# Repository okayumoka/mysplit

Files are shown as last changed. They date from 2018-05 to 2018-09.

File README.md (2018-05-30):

# MySplit Keyboard

自作の左右分割型キーボードです。
筐体（ケース）、Arduino Micro用ファームウェア、レイアウト変更用ツールのセットです。
ビルド方法はこのREADMEを参照してください。

この自作キーボードは、基盤（PCB）を使わず、空中配線するようになっています。
半田付けの難易度は高くないと思います。

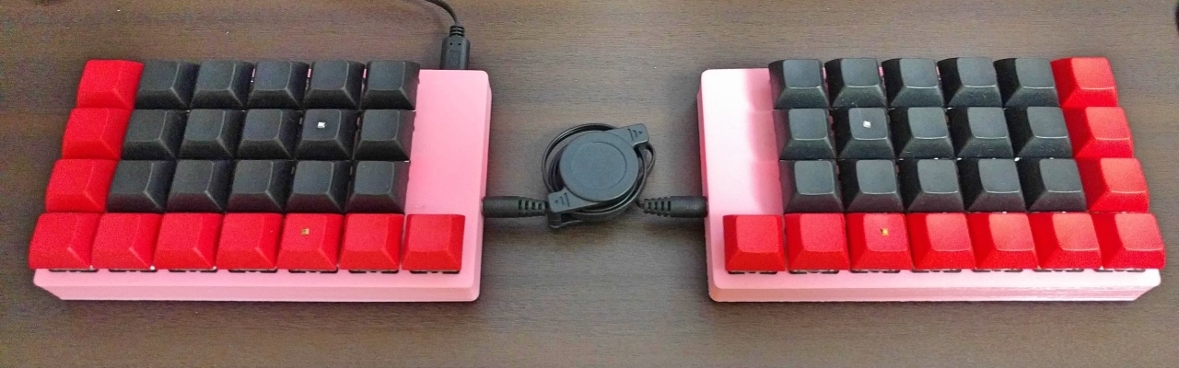
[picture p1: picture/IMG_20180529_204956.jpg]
完成品の一例


# 特徴など

自作キーボードとしてはあまり特徴の無い、 左右分割型の格子配列です。

4x6+1配列で、Let's Splitに親指用キーが一つ増えた形です。4行版Helixと同じです。

左右で1台ずつ、計2台のProMicroを使用します。
左手側がホストのため、使用時は左手側のProMicroをUSBで接続します。
右手側のProMicroを接続しても動きません。

左右のキーボードはステレオミニケーブル（3極ケーブル）で接続します。4極ケーブルは必要ありません。
3極ケーブルでないと動かないわけではなく、4極ケーブルでも動作はします。

筐体に自前の3Dプリンターを用いる場合は、、好きな色で作ることができます。
キーキャップとのいろいろな組み合わせが楽しめます。

# 準備物

このリポジトリの内容物に加えて、以下のものが必要です。

## 部品
* ProMicroまたはその互換機 2台
* ダイオード（1N4148または1SS178）
* Cherry MX キースイッチ（または、その互換スイッチ）
* キーキャップ
* 配線用ケーブル
* [3.5mm 4極ミニジャック 基板取付用 MJ-4PP-9](http://akizukidenshi.com/catalog/g/gC-06070/)（メーカー：AVVICON ELECTRONIC CORPORATION、秋月電子で購入可能）
* 3.5mm ステレオミニケーブル（音楽用のケーブルで構いませんが、モノラルでは駄目です）
* M3ネジ 長さ8mm ×8本（筐体の蓋固定用）
* M3ネジ 長さ5mm ×2本（ProMicro固定用）

Arduino Microは左右に一つずつ、合計2台必要です。
ダイオード、キースイッチ、キーキャップはキーの数だけ必要です。

## 工具・その他
* 半田ごて、半田
* ヤスリ、カッター（筐体の微調整用）
* 瞬間接着剤
* セメダイン スーパーX
* 3Dプリンター（なくてもOK）

筐体（ケース）を印刷するために3Dプリンターを利用しますが、
無い場合は[DMM.make](https://make.dmm.com/print/)などの3Dプリントサービスを利用したのでも問題ありません。
むしろ多くの場合、そのほうが精度の高い筐体を入手できるでしょう。

## 入手先

部品、工具の入手先の一例です。

* [TALP KEYBOARD](https://talpkeyboard.stores.jp/)
  * ProMicro互換機、ダイオード、キースイッチ、キーキャップとすべて揃います。
  * AliExpressと比べるとさすがに高いですが、すぐ発送してくれる・国内配送なので安心感があります。
* [AliExpress](https://www.aliexpress.com/)
  * ダイオード以外をAliExpressで買うと一番安く収まると思います。
  * ただ中国からの購入になるため利用には注意。
* [秋月電子](http://akizukidenshi.com/catalog/default.aspx)
  * ダイオード、半田付けの道具、配線用ケーブルなどは定番の秋月で良いかと思います。
  * 3.5mm 4極ミニジャック 基板取付用 MJ-4PP-9 はここで購入してください。
  * 安く揃えるなら以下がおすすめです。
    * 高速スイッチング・ダイオード　１ＳＳ１７８（１００本入）
    * 半田ごて：ニクロムはんだこて　ＫＳ－３０Ｒ（３０Ｗ）
    * 半田：はんだ　０．８ｍｍ SD-62
    * こて台：はんだこて台　ＳＴ－１１
    * ケーブル：スズメッキ線0.6mm、耐熱電子ワイヤー2m×7色
* [Amazon](https://www.amazon.co.jp/)
  * キーキャップ、半田付けの道具などは入手できます。
  * 自分で組み立てるタイプの3Dプリンターも比較的安く手に入ります。RepRapで検索すると吉です。

3極ケーブルで接続できるにもかかわらず、ジャックに4極のものを利用しているのは、
単純に最初は4極ケーブルを使用するつもりだったからです。
もし同サイズの3.5mm ステレオミニジャックがあれば、それを利用しても問題ありません。

# ビルド手順

## 1.筐体の印刷

`case` 配下の3Dモデルが筐体となっています。
3Dプリンターか、3Dプリントサービスを利用して出力します。

自前の3Dプリンターで印刷する場合、素材はPLAがおすすめです。
キーボード筐体は平たく、薄いため、熱収縮の大きいABSで反らないように印刷することは至難の技です。

3Dプリントサービスを利用する場合は、特に素材に縛りはありませんが、
価格を考えるとナイロンが無難でしょう（2018年5月現在の値段を見る限り）。

## 2.キースイッチはめ込み

筐体の穴にCherry MXキースイッチをはめ込みます。

3Dプリンターの精度によっては穴のサイズがまちまちなので、ヤスリとカッターで調整します。
削りすぎないようにだけ注意してください。

キースイッチについている爪が引っかかるように、筐体には凹みがついていますが、
爪だけではキーキャップを交換したいときにも抜けてしまうので、
瞬間接着剤等で固定してしまうのが良いかと思います。

## 3.ミニジャック固定

3.5mm 4極ミニジャックを筐体に固定します。穴の部分は多少ヤスリで調整が必要になると思います。
固定は瞬間接着剤がおすすめです。

## 4.配線（半田付け）

回路図(`circuit_diagram`配下のファイル参照)通りに配線していきます。
ダイオードの向きに注意してください。
キースイッチから伸びている先の数字は、ProMicroのピン番号です。

回路図は、スイッチを筐体にはめ込んで裏返した状態となっています。
表から見た状態ではないので注意してください。

また、ProMicroの互換品はMicro USBジャックが折れやすいものが多いですので、
セメダイン スーパーXなどで固定してしまうのがおすすめです。

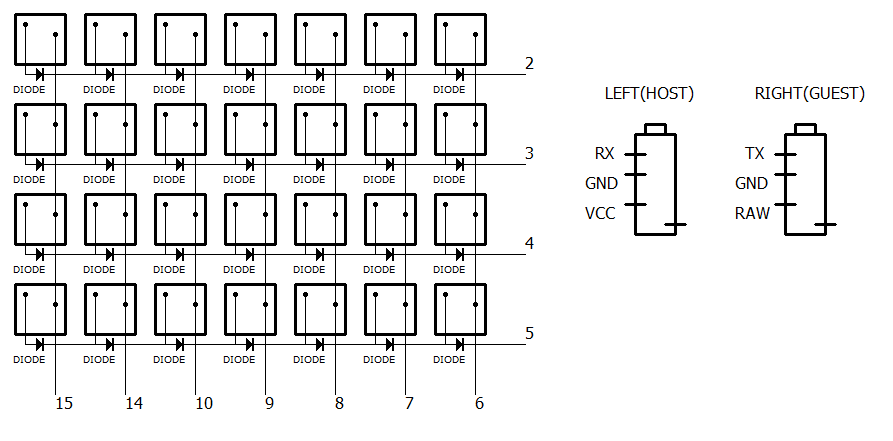
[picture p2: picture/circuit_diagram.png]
回路図


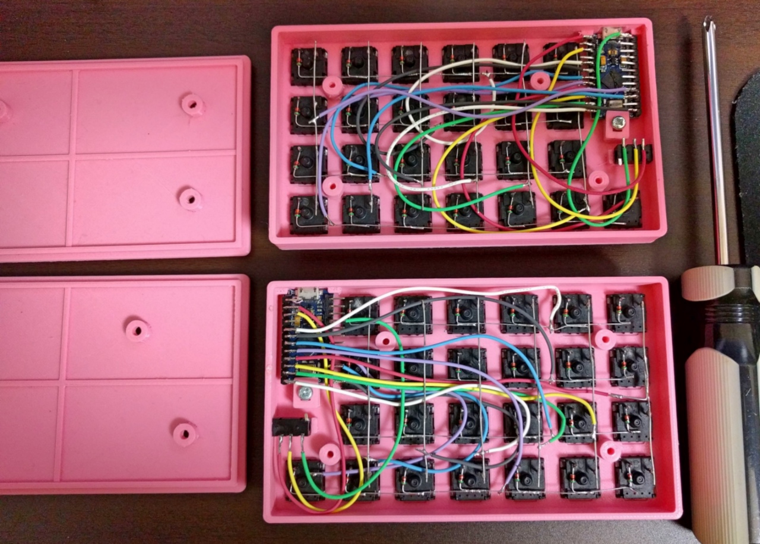
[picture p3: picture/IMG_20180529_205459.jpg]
配線した状態


## 5.ファームウェア書き込み

`firmware`配下のファームウェアをProMicroに書き込みます。
書き込みには、[Arduino IDE](https://www.arduino.cc/)などを利用してください。

Arduino IDEの使い方、スケッチの書き込み方法等はここでは解説しません。
注意点として、書き込み時に SparkFun ProMicro か Arduino Micro を選択するのを忘れないでください。

【重要】
ファームウェアは左手用と右手用で共通となっており、
書き込み時に切り替えるようになっています。
左手側に書き込む際はソースコードの `#define HOST_SIDE` を有効にします。
右手側に書き込むときは、`#define HOST_SIDE` をコメントアウトします。

書き込み後、動作確認を行ってください。

## 6.ProMicro固定、裏蓋装着

ProMicro固定用の部品とネジで固定します。
グラつくときは、固定用部品を瞬間接着剤で接着してしまうのが良いです。

その後、裏蓋をネジ止めします。

## 7.キーキャップはめ込み

お好みのキーキャップを取り付けて、完成です。

## 8.キー配列変更

キー配列の変更には、`tools/layouteditor` を使用します。

各キーをマウスでクリックして選択後、下側のキーボード部分をクリックすると、
選択したキーが割り当てられます。
Lower/Normal/Upperレイヤは、中央部のボタンによって切り替えます。

`Generate & Download`ボタンで、ソースコード（`keymap.ino`）を出力します。
出力されたファイルを、`firmware` 配下の同じ名前のファイルに上書きして、
ファームウェアを再書き込みしてください。

## License

MIT License

Copyright (c) 2018 okayu

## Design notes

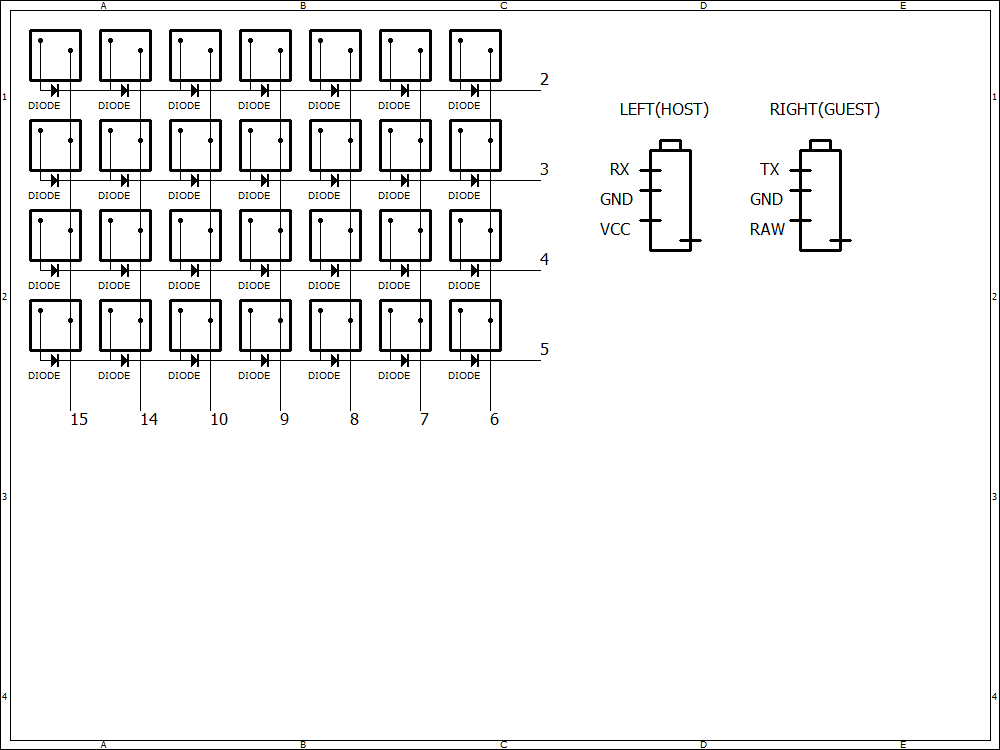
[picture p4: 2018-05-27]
circuit_diagram/circuit_diagram.png

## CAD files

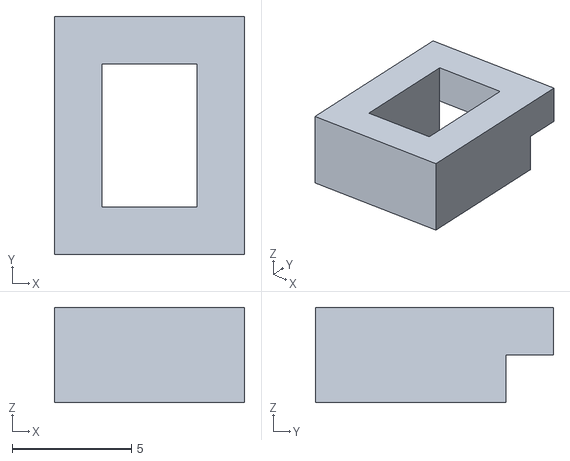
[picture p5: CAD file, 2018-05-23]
case/ProMicro.stl
8.00 x 10.0 x 4.00

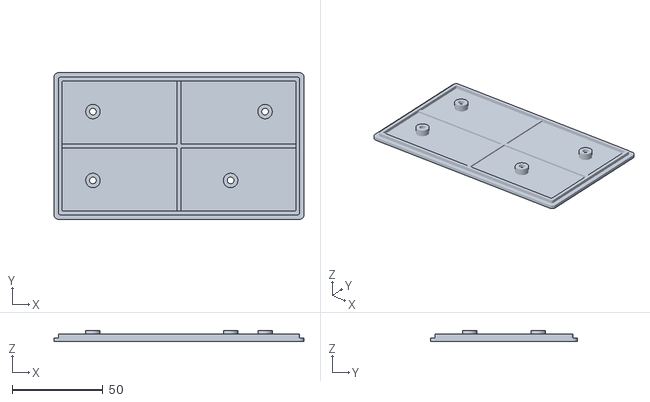
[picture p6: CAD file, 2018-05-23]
case/under_right.stl
138.0 x 81.0 x 6.00

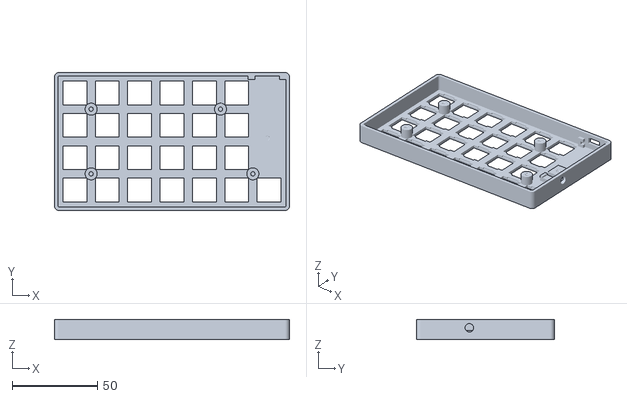
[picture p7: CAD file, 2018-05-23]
case/upper_right.stl
138.0 x 81.0 x 12.0

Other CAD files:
case/upper.stl
case/under.stl

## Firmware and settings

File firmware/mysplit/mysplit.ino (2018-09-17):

// MySplit

#include "Keyboard.h"
#include "keymap.h"

const int rowPins[ROW_NUM] = { 2, 3, 4, 5 }; // OUTPUTのピン。走査ピン
const int colPins[COL_NUM] = { 6, 7, 8, 9, 10, 14, 15 }; // INPUT_PULLUPのピン。

bool currentState[ROW_NUM][COL_NUM_2]; // 現在のループでの押下状態
bool beforeState[ROW_NUM][COL_NUM_2];  // 前のループでの押下状態
int pressedKeyCode[ROW_NUM][COL_NUM_2]; // 押下したキー
unsigned long pressedKeyTime[ROW_NUM][COL_NUM_2]; // 押下してからの経過時間（マイクロ秒）
bool raiseLayerKey = 0;
bool lowerLayerKey = 0;

#define IGNORE_TIME_MICROS 16000 // 押下状態の変化を無視する時間（マイクロ秒）

void setup() {
    for (int i = 0; i < ROW_NUM; i++) {
        int pin = rowPins[i];
        pinMode(pin, OUTPUT);
        digitalWrite(pin, HIGH);
    }
    for (int i = 0; i < COL_NUM; i++) {
        int pin = colPins[i];
        pinMode(pin, INPUT_PULLUP);
    }

    for (int i = 0; i < ROW_NUM; i++) {
        for (int j = 0; j < COL_NUM_2; j++) {
            currentState[i][j] = HIGH;
            beforeState[i][j] = HIGH;
            pressedKeyCode[i][j] = KC_NULL;
            pressedKeyTime[i][j] = 0;
        }
    }

    Serial.begin(9600);
    Serial1.begin(9600);
    Keyboard.begin();
}

void loop() {
    getThisSideState();
    sendThisSideState();
    getOtherSideState();
    applyKeyState();
}

void getThisSideState() {
    for (int i = 0; i < ROW_NUM; i++) {
        int rowPin = rowPins[i];
        digitalWrite(rowPin, LOW);
        for (int j = 0; j < COL_NUM; j++)  {
            int colPin = colPins[j];
            currentState[i][j] = digitalRead(colPin);
        }
        digitalWrite(rowPin, HIGH);
    }
}

void getOtherSideState() {
    while (true) {
        if (!Serial1.available()) break;

        byte readData = Serial1.read();
        if (readData == -1) break;

        // 通信方式について
        // 0bABCDEFGH
        // AB  ... 状態。00:無効 01:Press 10:Release 11:後続データなし
        // CDE ... rowPinの番号（右手用の範囲内で。したがって0～5）
        // FGH ... colPinの番号（右手用の範囲内で。したがって0～6）

        // bool eof     = (bool) ((readData & 0b10000000) == 0b10000000);
        // bool isPress = (bool) ((readData & 0b01000000) == 0b00000000);
        int state    = (int)  ((readData & 0b11000000) >> 6);
        int rowPin   = (int)  ((readData & 0b00111000) >> 3);
        int colPin   = (int)  ( readData & 0b00000111 );

        bool eof = (state == 0b11) || (state == 0b00);
        bool isPress = state == 0b01;
        if (rowPin >= ROW_NUM) rowPin = ROW_NUM - 1;
        if (colPin >= COL_NUM) colPin = COL_NUM - 1;

        if (eof) { break; }

        // Serial.print("Receive: ");
        // Serial.print(readData, BIN);
        // Serial.print(" r=");
        // Serial.print(rowPin);
        // Serial.print(" c=");
        // Serial.print(colPin);
        // Serial.print("  ->  ");

        // printKeyEvent(rowPin, colPin, isPress, 0);
        // ホスト：左手、サブ：右手
        currentState[rowPin][colPin + COL_NUM] = isPress ? LOW : HIGH;
    }
}
void applyKeyState() {
    // Raise Layer、Lower Layer が押されているかを取得
    for (int i = 0; i < ROW_NUM; i++) {
        for (int j = 0; j < COL_NUM_2; j++)  {
            if (currentState[i][j] != beforeState[i][j]) {
                if (keyMap[i][j] == KC_RISE) {
                    raiseLayerKey = currentState[i][j] == LOW;
                    beforeState[i][j] = currentState[i][j];
                }
                if (keyMap[i][j] == KC_LOWR) {
                    lowerLayerKey = currentState[i][j] == LOW;
                    beforeState[i][j] = currentState[i][j];
                }
            }
        }
    }
    int layer = 0; // -1: Lower  0: Base  1: Raise
    if (raiseLayerKey) layer++;
    if (lowerLayerKey) layer--;

    // キーを送る
    int keyCode;
    for (int i = 0; i < ROW_NUM; i++) {
        for (int j = 0; j < COL_NUM_2; j++)  {
            // チャタリング防止のための待ち処理
            if (pressedKeyTime[i][j] > 0) {
                unsigned long elapsed = micros() - pressedKeyTime[i][j];
                if (elapsed < IGNORE_TIME_MICROS) {
                    continue;
                } else {
                    pressedKeyTime[i][j] = 0;
                }
            }
            // 押下状態の変化を検出してキーを送る
            if (currentState[i][j] != beforeState[i][j]) {
                if (currentState[i][j] == LOW) {
                    if (layer == 0) keyCode = keyMap[i][j];
                    else if (layer > 0) keyCode = keyMapRaise[i][j];
                    else if (layer < 0) keyCode = keyMapLower[i][j];
                    // keyCode = currentMap[i][j];
                    if (keyCode == KC_NULL) keyCode = keyMap[i][j];
                    if (keyCode == KC_RISE) continue;
                    if (keyCode == KC_LOWR) continue;

                    pressedKeyCode[i][j] = keyCode;
                    pressedKeyTime[i][j] = micros();

                    if (keyCode == KC_CTSP)  {
                        // 特殊キー Ctrl+Space の押下
                        Keyboard.press((char) KC_LCTL);
                        Keyboard.press((char) KC_SPC);
                        // 特殊キー Ctrl+Space の即時リリース
                        Keyboard.release((char) KC_SPC);
                        Keyboard.release((char) KC_LCTL);
                        delay(1);
                    } else {
                        // 通常キーの押下
                        Keyboard.press((char) keyCode);
                    }
                    // printKeyEvent(i, j, true, layer);
                    // printPressedKey(keyCode);
                } else {
                    keyCode = pressedKeyCode[i][j];
                    pressedKeyCode[i][j] = KC_NULL;

                    if (keyCode == KC_CTSP)  {
                        // 特殊キー Ctrl+Space のリリース
                        // 即時リリース扱いでリリースされているので処理不要
                    } else {
                        // 通常キーのリリース
                        Keyboard.release((char) keyCode);
                    }
                    // printKeyEvent(i, j, false, layer);
                    // printPressedKey(keyCode);
                }
            }
            beforeState[i][j] = currentState[i][j];
        }
    }
}

void sendThisSideState() {
    if (!Serial1.availableForWrite()) return;

    bool sentFlag = false;
    int state;
    byte sendData = 0b00000000;

    for (int i = 0; i < ROW_NUM; i++) {
        for (int j = 0; j < COL_NUM; j++) {
            if (currentState[i][j] != beforeState[i][j]) {
                if (currentState[i][j] == LOW) {
                    // printKeyEvent(i, j, true, 0);
                    state = 0b01000000;
                } else {
                    // printKeyEvent(i, j, false, 0);
                    state = 0b10000000;
                }
                sendData = (byte) (state | i << 3 | j);
                sentFlag = true;
                // Serial.print("Send: ");
                // Serial.println(sendData);
                Serial1.write(sendData);
            }
            //beforeState[i][j] = currentState[i][j];
        }
    }
    if (sentFlag) Serial1.write(0b11111111); // 後続データなしを送信
}

void printKeyEvent(int row, int col, bool isPress, int layer) {
    if (isPress) {
        Serial.print("PRESS   (");
    } else {
        Serial.print("RELEASE (");
    }
    Serial.print(row);
    Serial.print(", ");
    Serial.print(col);
    Serial.print(", ");
    Serial.print(layer);
    Serial.println(")");
}

void printPressedKey(byte keyCode) {
    Serial.print("    KEYCODE: ");
    Serial.println(keyCode);
}

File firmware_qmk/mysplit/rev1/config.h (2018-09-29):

/*
Copyright 2012 Jun Wako <wakojun@gmail.com>
Copyright 2015 Jack Humbert

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
You should have received a copy of the GNU General Public License
along with this program.  If not, see <http://www.gnu.org/licenses/>.
*/

#ifndef REV1_CONFIG_H
#define REV1_CONFIG_H

#include "config_common.h"

/* USB Device descriptor parameter */
#define VENDOR_ID       0xFEED
#define PRODUCT_ID      0x7770
#define DEVICE_VER      0x0001
#define MANUFACTURER    okayu
#define PRODUCT         MySplit v1
#define DESCRIPTION     A split keyboard for me

/* key matrix size */
// Rows are doubled-up
#define MATRIX_ROWS 8
#define MATRIX_COLS 7

// wiring of each half
#define MATRIX_ROW_PINS { D1, B2, D4, C6 }
#define MATRIX_COL_PINS { D7, E6, B4, B5, B6, B3, B1 }
// #define MATRIX_COL_PINS { B3, B1, F7, F6, F5, F4 } //uncomment this line and comment line above if you need to reverse left-to-right key order

/* define if matrix has ghost */
//#define MATRIX_HAS_GHOST

/* number of backlight levels */
// #define BACKLIGHT_LEVELS 3

/* Set 0 if debouncing isn't needed */
#define DEBOUNCING_DELAY 5

/* Mechanical locking support. Use KC_LCAP, KC_LNUM or KC_LSCR instead in keymap */
#define LOCKING_SUPPORT_ENABLE
/* Locking resynchronize hack */
#define LOCKING_RESYNC_ENABLE

/* key combination for command */
#define IS_COMMAND() ( \
    keyboard_report->mods == (MOD_BIT(KC_LSHIFT) | MOD_BIT(KC_RSHIFT)) \
)

/* ws2812 RGB LED */
#define RGB_DI_PIN D3
#define RGBLIGHT_TIMER
#define RGBLED_NUM 16    // Number of LEDs
#define ws2812_PORTREG  PORTD
#define ws2812_DDRREG   DDRD

/*
 * Feature disable options
 *  These options are also useful to firmware size reduction.
 */

/* disable debug print */
// #define NO_DEBUG

/* disable print */
// #define NO_PRINT

/* disable action features */
//#define NO_ACTION_LAYER
//#define NO_ACTION_TAPPING
//#define NO_ACTION_ONESHOT
//#define NO_ACTION_MACRO
//#define NO_ACTION_FUNCTION

#endif

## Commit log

2018-01-16 動作未検証
2018-01-16 とりあえず送れるように
2018-01-18 多分だいたい動くように
2018-02-09 ツール作りかけ
2018-03-04 回路図修正
2018-03-09 取りあえず形に
2018-03-09 キー入力が送れる問題の修正
2018-03-12 キーコード、配列を少し修正
2018-03-21 キーマップを更新
2018-03-21 Upper -> Raiseに名称変更
2018-03-21 筐体のSTLファイルを追加
    [MySplit_ProMicro止め.stl, MySplit_上面.stl, MySplit_下面.stl]
2018-03-26 チャタリングの対策を実装
2018-03-27 レイアウト案を追加
2018-04-05 レイアウト変更
2018-04-14 フォルダ分けを見直し
    [MySplit_ProMicro止め.stl, MySplit_上面.stl, MySplit_下面.stl]
2018-04-14 ファームウェア暫定
2018-04-14 ツール更新
2018-04-14 ケース追加
    [ProMicro.stl, under.stl, under_right.stl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]
2018-05-01 Ctrl+Spaceの特殊キーを追加
2018-05-05 2: Auto stash before merge of "Prototype2" and "origin/Prototype2"
2018-05-18 MacだとCtrl+Spaceの反応が悪かった問題を修正
2018-05-23 Readme執筆中
2018-05-26 とりあえず書いた
2018-05-26 ボタンなどを整理
2018-05-27 配線図 画像を追加
2018-05-27 選択しているレイヤが赤字で出るように
2018-05-27 README更新
2018-05-27 未完成の5x6配列関係のファイルを削除
    [MySplit_ProMicro止め.stl, MySplit_上面.stl, MySplit_下面.stl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]
2018-05-30 写真を追加
2018-08-08 チャタリング防止の処理を少しまともに修正
2018-08-08 チャタリング対策の時間を調整
2018-09-17 左右同じプログラムで動くように

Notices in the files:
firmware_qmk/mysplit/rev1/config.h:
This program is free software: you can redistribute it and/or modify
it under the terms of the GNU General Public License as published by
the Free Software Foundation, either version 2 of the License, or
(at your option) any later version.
